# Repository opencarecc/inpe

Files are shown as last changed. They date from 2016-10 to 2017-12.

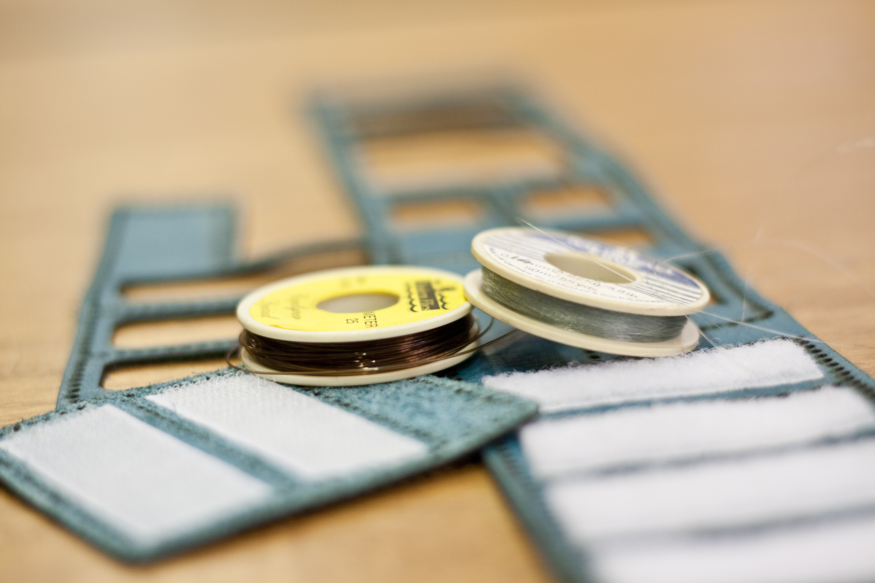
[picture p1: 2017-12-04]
pictures/_MG_0598.jpg

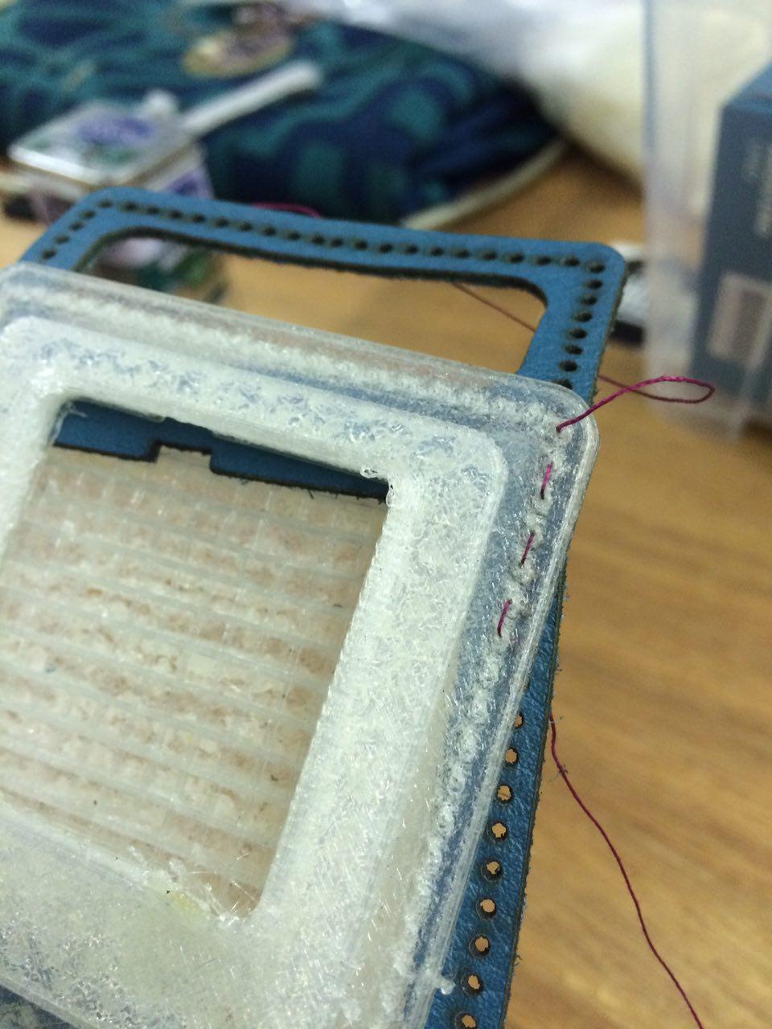
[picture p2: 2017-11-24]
pictures/Inpe_confezione.jpg

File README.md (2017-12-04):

# InPe' @ opencare.cc
InPe' is a wearable device that detects fall and call for emergecy.

InPe' has been ideated and designed by communities living in the city of Milan (Italy), and developed by [WeMake](http://wemake.cc/) in the framework of the [opencare.cc](http://opencare.cc/) project.

InPe' is open source. Please read below for licensing details.

## References
* More info about the opencare.cc project can be found here <http://opencare.cc>
* More info about the InPe' prototype can be found here <http://inpe.opencare.cc>
* Tutorials about InPe' can be found here <https://github.com/opencarecc/inpe/wiki>

## Software
The InPe' prototype is built on top of the *RePhone* hardware by Seeed Studio.
More info on how to get started with the RePhone and the RePhone development environment can be found in the wiki section of the repo <https://github.com/opencarecc/inpe/wiki>

In the **software** folder of the repository are various Arduino *.ino* sketches, all of them can be ran by the RePhone hardware:
* in the **software** root folder are the updated main sketches of the InPe' prototype (the "InPe-T\*" versions have been implemented for the user testing campaign)
* in the **utilities** folder is a collection of sketches to test, calibrate and debug the hardware. They are useful to setup and customize an InPe', and for developers willing to contribute to the project to learn more about the library.

## Hardware
In the hardware section of the repository are the source files for the case *[coming soon...]*

## Bug reporting and Contributions
If you want to report a bug please do so in the *[Issues](https://github.com/opencarecc/inpe/issues)* section of the repository (<https://github.com/opencarecc/inpe/issues>) and mark it with a *BUG* label. Before adding a bug please do a quick search under the *BUG* label to check for known issues and avoid duplicates.

If you want to contribute please have a look under the *TO DO* and *WISH* labels to see what features are in the pipeline and what is the status of their development.

If you want to contribute with a new feature please open a new issue under the *PROPOSAL* label explaining about it.

## License

Copyright (C) 2016 WeMake

### Software

This program is free software: you can redistribute it and/or modify it under the terms of the [GNU General Public License](https://www.gnu.org/licenses/gpl-3.0.en.html) as published by the Free Software Foundation, either version 3 of the License, or any later version.

This program is distributed in the hope that it will be useful, but WITHOUT ANY WARRANTY; without even the implied warranty of MERCHANTABILITY or FITNESS FOR A PARTICULAR PURPOSE.  See the
    GNU General Public License for more details.

You should have received a copy of the GNU General Public License along with this program.  If not, see <http://www.gnu.org/licenses/>.

### Hardware

Copyright 2016 WeMake.

This documentation describes an Open Hardware and is licensed under the CERN OHL v. 1.2.

You may redistribute and modify this documentation under the terms of the CERN OHL v.1.2. ([http://ohwr.org/cernohl]()). 
This documentation is distributed WITHOUT ANY EXPRESS OR IMPLIED WARRANTY, INCLUDING OF MERCHANTABILITY, SATISFACTORY QUALITY AND FITNESS FOR A PARTICULAR PURPOSE. Please see the CERN OHL v.1.2 for applicable conditions

## Contacts

You can get in touch with us on the InPe' [website](http://inpe.opencare.cc/#comments) or by writing at: 
opencare [@] wemake [dot] cc

-----



This project has received funding from the European Union's Horizon 2020 research and innovation programme under grant agreement No 688670.

-----

*THANKS!*

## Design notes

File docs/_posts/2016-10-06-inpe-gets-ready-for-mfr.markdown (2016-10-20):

---
layout: post
title:  "In Pe gets ready for Maker Faire Rome"
date:   2016-10-06
categories: 
---

It has been several weeks now of In Pe development and we are getting close to finalizing our initial prototype before the Rome Makerfaire.  As you know, In Pe is a device developed as a result of WeMake’s hosted codesign sessions. It is based on a real story, where a caregiver was about to loose her mother, who fell down while being alone, and the caregiver couldn’t be alarmed. The existing market solutions are sometimes “embarrassing” or not appealing enough or not comfortable to wear, which makes them less efficient, as the person in need of care, will simply avoid them. In Pe (which means Standing Up
in Italian), is a simple opensource, customizable device, that can help caregiver stay in touch with their loved ones, while keeping in mind that the designed solution is appealing enough for the person who needs care, so that they are actually using it.

Our solution simply depends on detecting a fall and calling a caregiver. Once the fall is detected, then this person will receive a call that the person fell down and the caregiver can react.   Our particular solution is  designed as a bracelet that the elderly or person who needs care can wear in his wrist, but we are currently checking other forms of usability that can fit different needs.

The project is composed of a sensor that detects the fall, a GSM module that sends a signal when a fall action is detected, and then the caregiver received a call.   All hardware and code is opensource.  It is not a newbie level kind of opensource project, but through documentation and some makerspace/fablab help, any caregiver is able to replicate and personalize it.

We are currently in testing phase where we are checking both the usability and the sensor accuracy.   We are testing different falling scenarios, such as testing to detect a fall while skateboarding, for example, we are also testing different usability scenarios, to check if the device could be sued for individuals with different needs.

Moving on, we will be developing different iterations of the device in order to both meet different needs of functionalities and to provide a different appeal for In Pe.  The Rome MakerFaire is almost a week ahead, where we look forward to have a chance to present our concept to a broad audience, receive more feedback, and get in touch with more future testers or replicators. Stay tuned to our next updates.

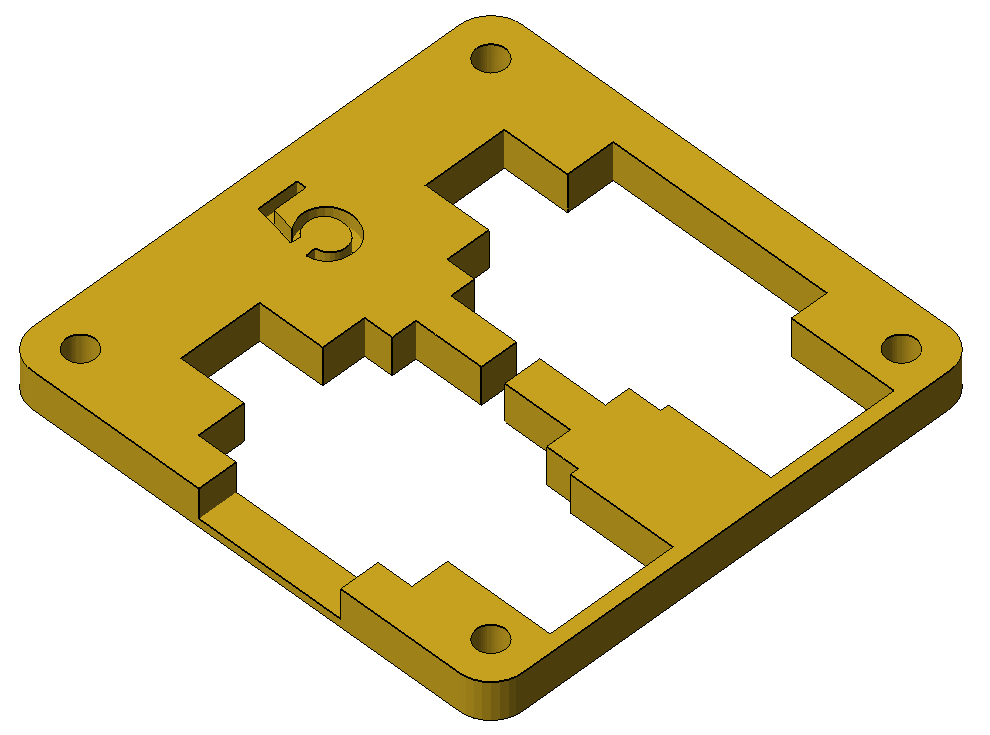
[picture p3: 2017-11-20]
pictures/InPe Layer 05.png

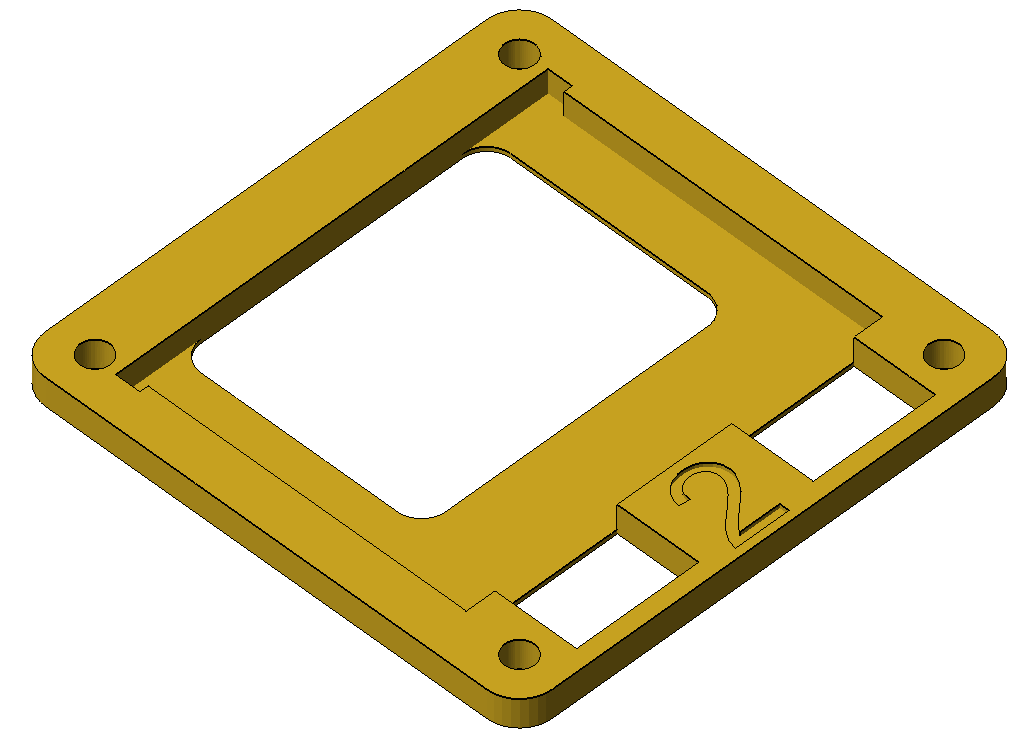
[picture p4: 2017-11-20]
pictures/InPe Layer 02.png

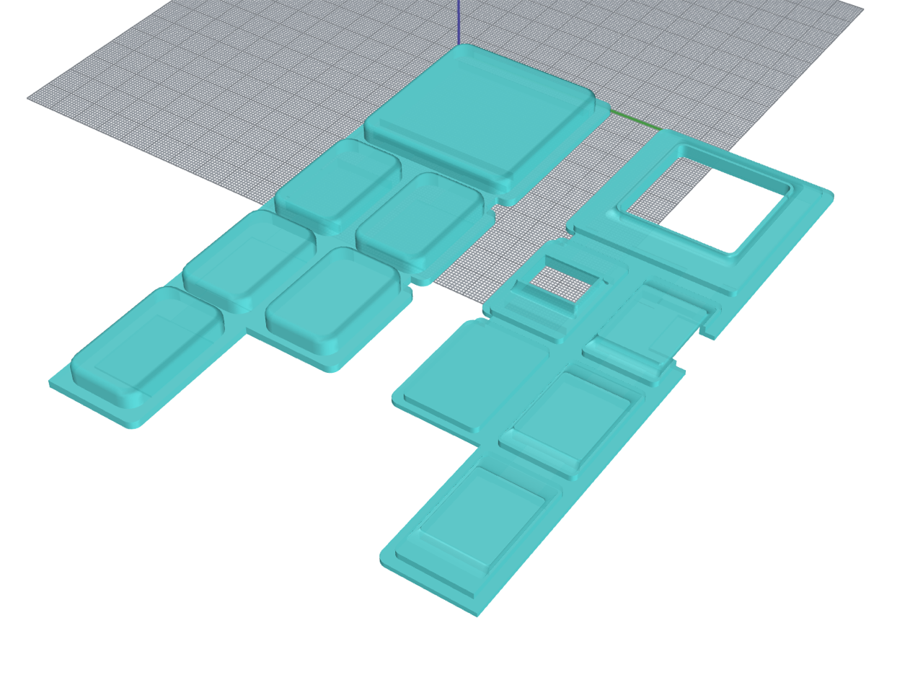
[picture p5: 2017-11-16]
pictures/Screen Shot 2017-11-15 at 20.33.19.png

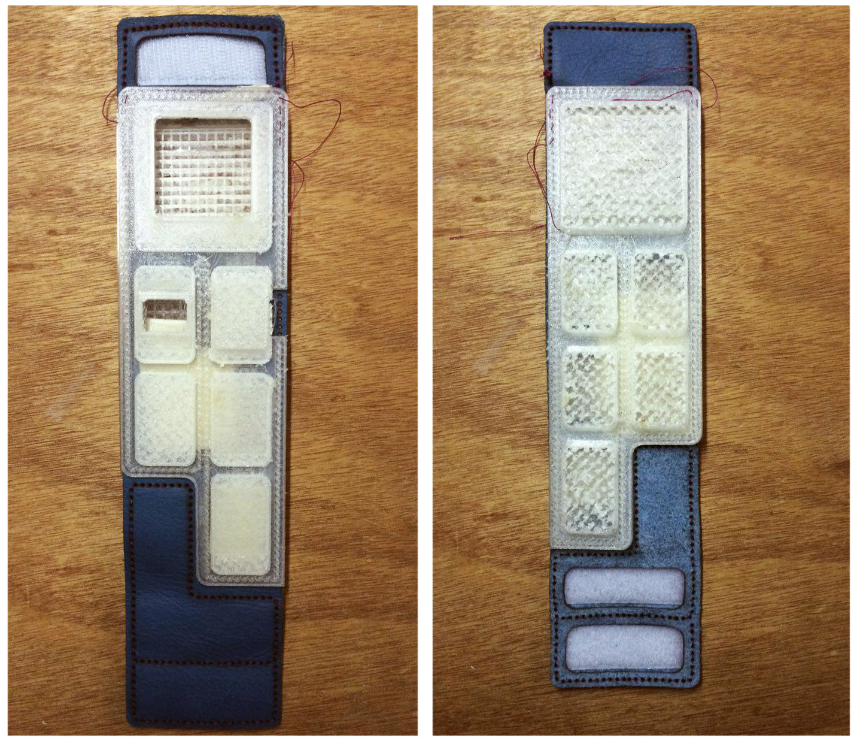
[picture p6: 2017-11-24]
pictures/Inpetest2.jpg

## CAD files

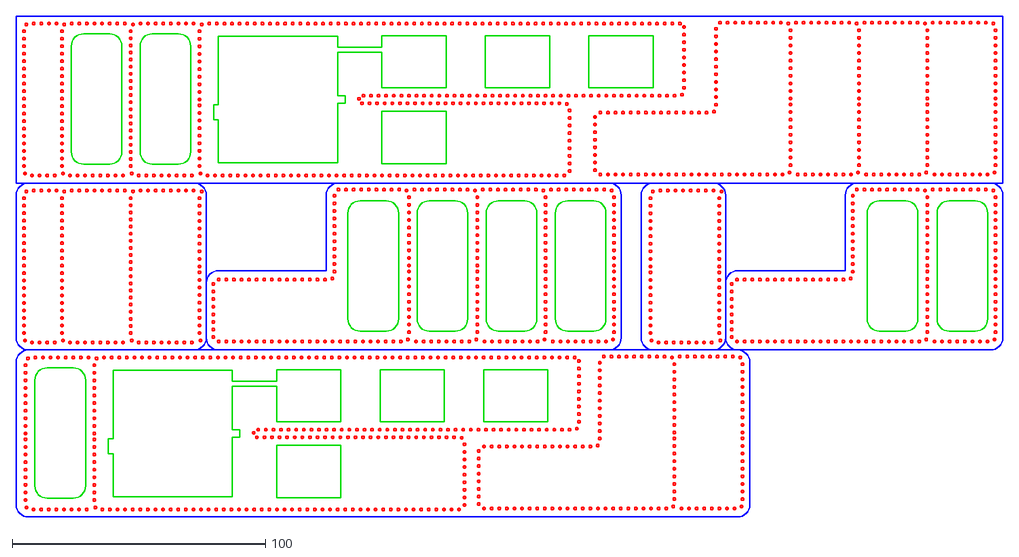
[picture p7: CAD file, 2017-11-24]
3Dmodels/IpEWristwatch.dxf
390.0 x 198.0

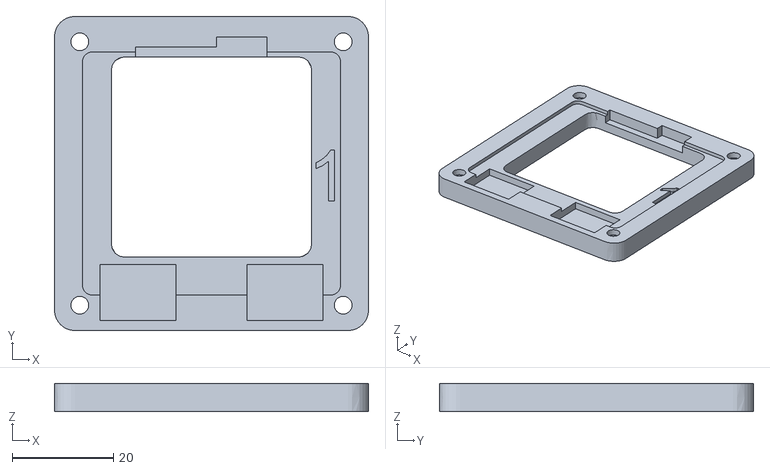
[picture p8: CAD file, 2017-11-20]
3Dmodels/inpe_ inner case 01.stl
62.0 x 62.0 x 5.60

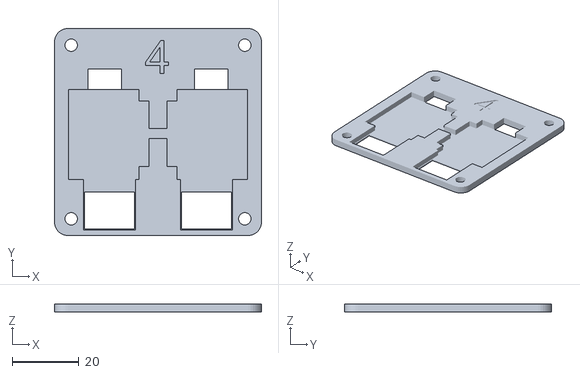
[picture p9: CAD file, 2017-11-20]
3Dmodels/inpe_ inner case 04.stl
62.0 x 62.0 x 2.50

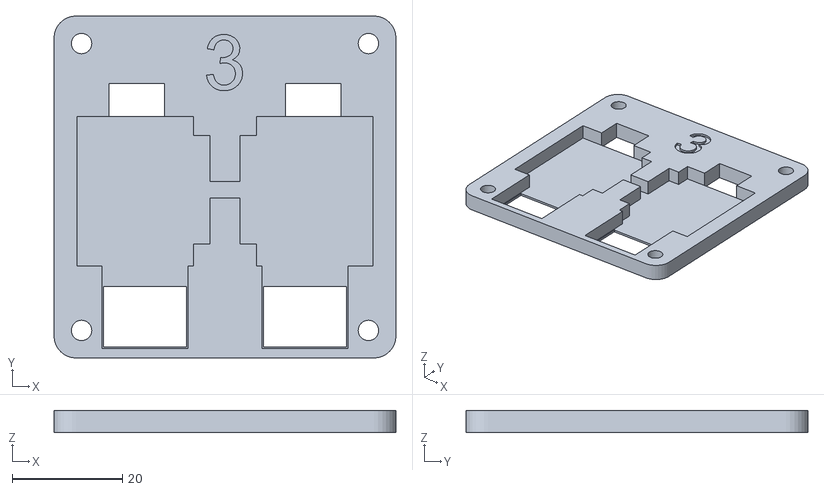
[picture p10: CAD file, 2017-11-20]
3Dmodels/inpe_ inner case 03.stl
62.0 x 62.0 x 4.00

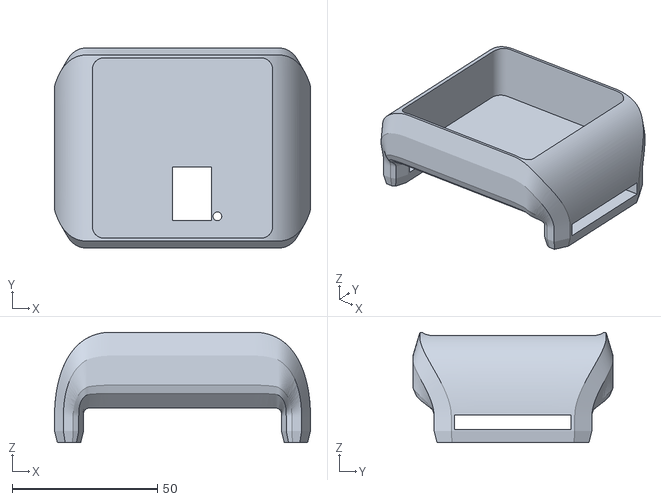
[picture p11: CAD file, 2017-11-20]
3Dmodels/inpe_ outer case 02.stl
88.0 x 68.8 x 38.0

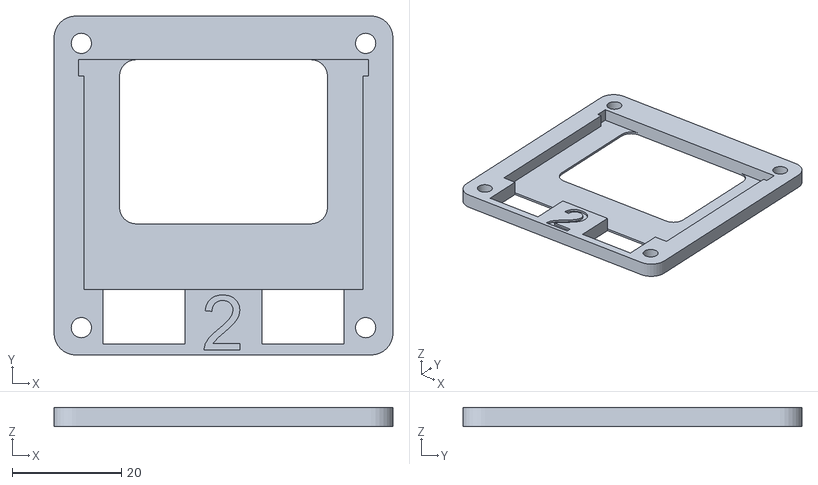
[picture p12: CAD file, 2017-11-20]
3Dmodels/inpe_ inner case 02.stl
62.0 x 62.0 x 3.50

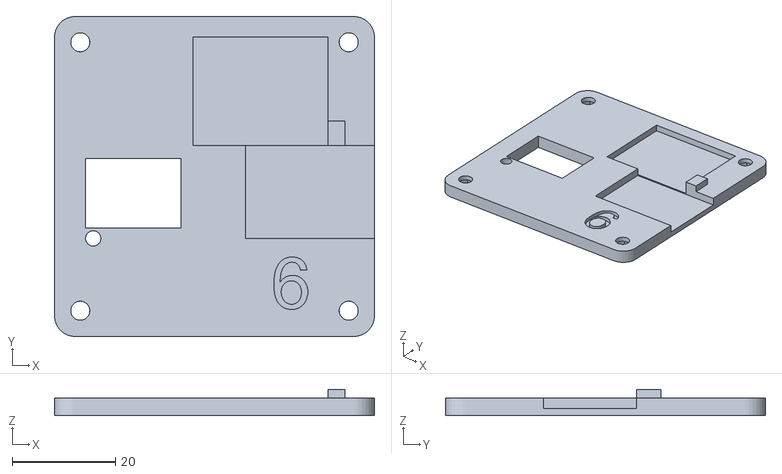
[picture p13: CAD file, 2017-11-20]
3Dmodels/inpe_ inner case 06.stl
62.0 x 62.0 x 5.10

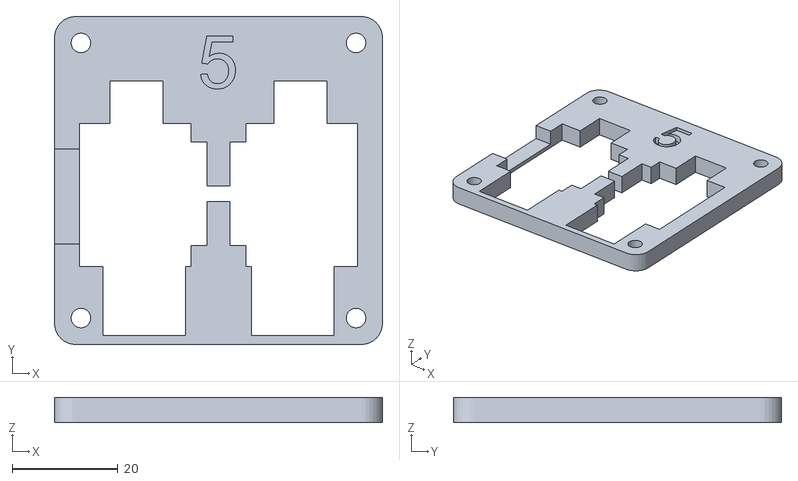
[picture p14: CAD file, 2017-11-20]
3Dmodels/inpe_ inner case 05.stl
62.0 x 62.0 x 4.80

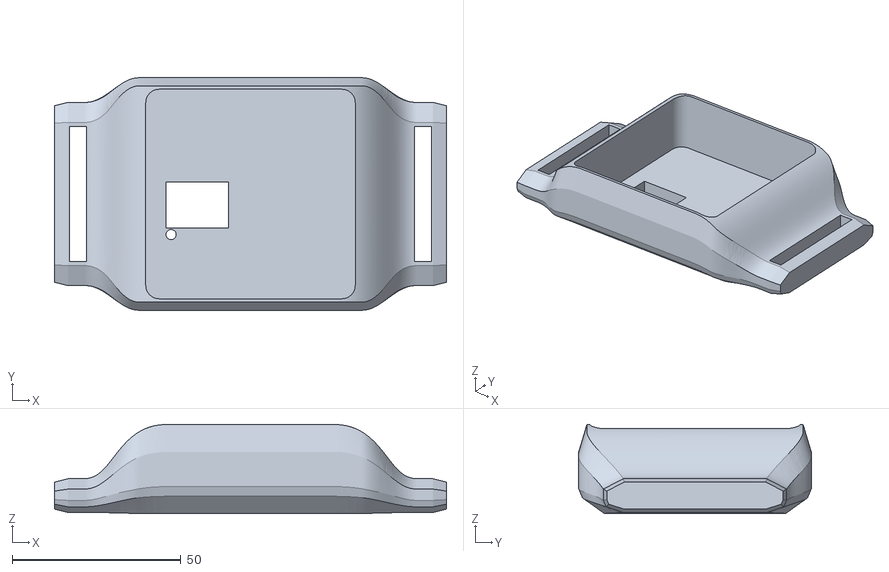
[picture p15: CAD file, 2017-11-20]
3Dmodels/inpe_ outer case 01.stl
116.0 x 68.8 x 26.4

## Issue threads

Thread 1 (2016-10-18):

fix fall detection algorithm

cntlsn, 2016-10-18:

cntlsn, 2016-12-06:
first iteration of the fall detection algorithm according to http://www.analog.com/en/analog-dialogue/articles/detecting-falls-3-axis-digital-accelerometer.html can be found here https://github.com/opencarecc/inpe/commit/b9420b699cf71949d21788917aed711021cbde0d

despite being more accurate, we decided to NOT go the interrupts way to make it more simple for future users to install their InPe' software

cntlsn, 2017-02-07:
fall detection algorithm according to http://www.analog.com/en/analog-dialogue/articles/detecting-falls-3-axis-digital-accelerometer.html can be found here https://github.com/opencarecc/inpe/commit/36d10e706345a82c4b3d9669377255bc116b8708

Closed 2017-02-07.

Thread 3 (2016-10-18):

rewrite GPS localization to save battery power

cntlsn, 2016-10-18:

cntlsn, 2016-12-06:
the first iteration can be found here https://github.com/opencarecc/inpe/commit/d5df8482466e7053867ff91c11b2a4eface8cad1
a clock library has been created. it keeps waiting for the GPS to pass UTC data, then starts a counter and displays the time on the LCD

cntlsn, 2016-12-06:
a second iteration can be found here https://github.com/opencarecc/inpe/commit/a7044c83d79ca759f0935d4938db9807c36e7a4e
it keeps waiting for the GPS to pass the UTC data, then sets the date and time using the DateTime library.
the DateTime library takes care of updating the time and date values

Closed 2017-02-07.

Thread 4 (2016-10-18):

turn off LCD display when not in use to save battery power

cntlsn, 2016-10-18:

cntlsn, 2016-12-06:
this has been solved in two ways

in https://github.com/opencarecc/inpe/commit/9147f1a338dcbac8146ef5f57f2e43f33f45e05f the sketch is just turning the backlight of the LCD up and down

in https://github.com/opencarecc/inpe/commit/54f33ccb3a6ad1112db7e96af79d8f1a146900ca the sketch is using the fuctions vm_pwr_lcd_sleep_in/out to turn the LCD on or off, but for some reason the LCD backlight stays always on.

this needs confirmation of power consumption in both approaches!

cntlsn, 2017-02-07:
solved with https://github.com/opencarecc/inpe/commit/5b25ce85826d4fd4b7289301ffba7571788a2cc8

Closed 2017-02-07.

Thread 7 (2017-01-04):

Create sketch to log power consumption with new Sleep Library

cntlsn, 2017-01-04:
Sleep library is here https://github.com/opencarecc/inpe/tree/5b25ce85826d4fd4b7289301ffba7571788a2cc8/software/utilities/Sleep_Library

cntlsn, 2017-01-05:
the cketch can be found here https://github.com/opencarecc/inpe/tree/a29eb10f5f5725b85c05a5a3da166cbd71b6fd56/software/utilities/Sleep_Library-Battery_Log

Closed 2017-01-05.

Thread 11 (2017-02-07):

[0.1-t03_10] sensor hub goes offline

cntlsn, 2017-02-07:
when removing/commenting the display on LCD of the Accelerometer Inactivity delta on line 403, the sensor hub tends go offline every once in a while for a some milliseconds

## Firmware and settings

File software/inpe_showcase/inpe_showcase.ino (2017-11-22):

/*
  This sketch is a fake version of InPe.
  It would turn useful when showing how it works to
  people at events without asking them to necessarily
  fall to the ground ;)
  
  HARDWARE:
  - Xadow GSM+BLE (with Antenna!)
  - Xadow 1.54" Touchscreen
  - Xadow Audio
  - Xadow GPS
  - Xadow Basic Sensors
  - Lipo battery 3.7v 520mAh
  - MicroSIM card
  
  !! ATTENTION !!
  To run this sketch extra libraries are required.
  - Please find them at https://github.com/opencarecc/inpe/tree/master/software/libraries
  Before uploading the sketch, please:
  - enter your phone number
  - enter date and time
  
  Alessandro Contini @ WeMake for http://opencare.cc/
  2017
*/

#include "LDisplayExt.h"
#include <LSensorHub.h>
#include <LAudio.h>
#include <LGTouch.h>
#include <LGPS.h>
#include <stdio.h>
#include <LCheckSIM.h>
#include <LGSM.h>
#include <LBattery.h>
//#include <LCFile.h>
#include <LDateTime.h>
#include "LSleep.h"

// initialize variables for GSM
char *phoneNumber = "enter-phone-number";

// initialize variables for Date and Time
// set time
unsigned int year     = 2017;
unsigned int month    = 11;
unsigned int day      = 6;
unsigned int hour     = 18;
unsigned int minute   = 7;
unsigned int sec      = 22;

datetimeInfo t;

char date[11];
char time[10];

// initialize variables for GPS UTC time data reading
unsigned char *utc_date_time = 0;
char bufferDateTime[30] = {0,};

unsigned int GPSyear      = 0;
unsigned int GPSmonth     = 0;
unsigned int GPSday       = 0;
unsigned int GPShour      = 0;
unsigned int GPSminute    = 0;
unsigned int GPSsec       = 0;

const int timeZone = +1;  // add here the amount of hours difference of your time zone compared to GMT
                          // if not sure about your time zone try this http://everytimezone.com/

boolean GPSDateTimeSynced = false;
boolean GPStimeConverted = false;

// initialize variables for audio module
#define    FILE_NAME    "rephone_audio.mp3"
int volume = 6;  // 0 is min, 6 is max volume

// initialize variables for touch event
char EVENT = 0;
int X = 0;
int Y = 0;

// initialize variables for accelerometer data
long accData1 = 0;  // will be used for X axis values
long accData2 = 0;  // will be used for Y axis values
long accData3 = 0;  // will be used for Z axis values

boolean fallFlag = false;   // alarm screen flag

boolean systemFlag = false; // system check flag

//boolean testFlag = false;   // test mode flag

// string to save the SMS SENT or NOT SENT data
char *SMSsentFeedback;
boolean smsSent = false;  // check to send SMS only once

// string to save the System Ready or System Error data
char *systemCheck;
unsigned int systemCheckStatus = 0;

// string to save the Sensor Hub Status (ON/OFF) data 
char *sensorHubStatus;
// string to save the GPS (ON/OFF) data 
char *GPSState;
// string to save the GPS (Sync/Ready/Error) data 
char *GPSStatus;

// string to save the SIM Status (OK/Error) data 
char *SIMStatus;

// set min and max coordinates for easier positioning on LCD screen
int xInit = 0;
int yInit = 0;
int xFinal = 240;
int yFinal = 240;



/* TEST MODE - FILE LOG STUFF */
// set a delay time to avoid flooding the log
int delayTime = 100;
// check number of loop runs
int numAccPrintRuns = 0;
int maxAccPrintRuns = 1;
// array to store chars for the file name
char fileName[21] = {0,};
// array to store chars for the heading of the txt file
char fileHeader[100] = {0,};
char writedata[40] = {0};  // will be used to print int the txt
// array to store the fall detection values
char detected[100] = {0, };
// var to store the status of Test Mode (0=OFF/1=ON) 
int testModeStatus = 0;

//////////////////////////////////////////////////////////
///////////////////////   SETUP   ////////////////////////
//////////////////////////////////////////////////////////

void setup()
{
  Serial.begin(115200);

  // Initialize Audio module
  LAudio.begin();
  LAudio.setVolume(volume);
  // play audio file to notify audio system is ready and device is ON
  LAudio.playFile(storageFlash, (char*)FILE_NAME);  

  // initialize touch
  Tp.Init();

  // initialize LCD
  LcdExt.init();
  LcdExt.font_init();
  LcdExt.back_light_level(100);
  LcdExt.screen_set(0x000000);

  // initialize Date and Time
  time_init();
  LDateTime.setTime(&t);
}

//////////////////////////////////////////////////////////
///////////////////////   LOOP   /////////////////////////
//////////////////////////////////////////////////////////

void loop()
{
  // check modules are connected and ready
  checkSensorHub();
  checkGPS();
  checkSIM();

  // show visual feedback if system ready or not
  checkSystem();

  // build home screen
  homeScreen();
  
  LcdExt.draw_updata();  // update screen 
}


//////////////////////////////////////////////////////////
////////////////   CHECK ACCELEROMETER   /////////////////
//////////////////////////////////////////////////////////
/* Check if Accelerometer is working */
boolean checkSensorHub() {
  switch(LSensorHub.check_on_line()){
    /* if Sensor Hub is not connected */
    case 0:                                           
      sensorHubStatus = "OFF  ";
      return false;
      break;
    /* if Sensor Hub is connected */
    case 1:                                           
      LSensorHub.GetAccData(&accData1, &accData2, &accData3);
      /* and if you are receiving values different than zero from the Accelerometer */  
      if (accData1!=0 && accData2!=0 && accData3!=0) {
        sensorHubStatus = "ON   ";
        return true;
        break;
      } else {
        sensorHubStatus = "ERROR";
        return false;
        break;
      }
      break;
  }
}


//////////////////////////////////////////////////////////
/////////////////////   CHECK GPS   //////////////////////
//////////////////////////////////////////////////////////
/* Check if GPS is working */
boolean checkGPS() {  
  switch(LGPS.check_online()){
    /* if GPS module is not connected */
    case 0:
      GPSState = "OFF";
      Serial.println("GPS is OFF");
      return false;
      break;
    /* if GPS module is connected */
    case 1:
      GPSState = "ON  ";
      /* if GPS Status is V(=navigation receiver warning) */
      if (LGPS.get_status()==86) {
          GPSStatus = "Sync  ";
          Serial.println("GPS is V");
      }
      /* if GPS Status is A(=Valid position) */
      else if (LGPS.get_status()==65) {
        GPSStatus = "Ready";
        Serial.println("GPS is A");
        return true;        
        break;
      } else {
        GPSStatus = "Error";
        Serial.println("GPS is ERROR");
      }
      break;
  }  
}


//////////////////////////////////////////////////////////
/////////////////////   CHECK SIM   //////////////////////
//////////////////////////////////////////////////////////
/* Check if a SIM card is inserted */
boolean checkSIM() {
  switch(LCheckSIM.isCheck()){
    /* if SIM is not inserted */
    case 0:
      SIMStatus = "Error";
      return false;
      break;
    /* if SIM is inserted */
    case 1:
      SIMStatus = "OK   ";
      return true;
      break;
  }
}


//////////////////////////////////////////////////////////
///////////////////   CHECK SYSTEM   /////////////////////
//////////////////////////////////////////////////////////
/* 
   If Xadow modules are connected and receiving
   correct data show visual feedback
*/
void checkSystem(){
  if(checkSensorHub()==true && checkGPS()==true && checkSIM()==true){
    systemCheck = "Ready :)";
    // if GPS available sync time with GPS UTC time
    GPStimeSync();      
//    return true;
    systemCheckStatus = 1;
  } else if(checkSensorHub()==true && checkGPS()==false && checkSIM()==true){
    systemCheck = "Ready :)";
    systemCheckStatus = 2;
  } else {
    systemCheck = "Error :(";
//    return false;
    systemCheckStatus = 3;
  }
}


//////////////////////////////////////////////////////////
////////////////////   HOME SCREEN   /////////////////////
//////////////////////////////////////////////////////////
void homeScreen(){
  Serial.println("Into Home Screen");
  
  // flush content by creating a new background
//  draw_rect(0,30,240,210,0x000000);
  LcdExt.draw_fill_rectangle(0,30,240,210,0x000000,0x000000);
  
  while(systemFlag==false && fallFlag==false){
    Serial.println("Into Home Screen While");
    
    createHeader();
    displayDate();
    displayTime();
    
    LcdExt.draw_font(87, 125, "InPe is", 0, 0xffffff, 20);
    if(checkSystem()==true){
      // font color green
//      draw_rect(50,150,147,40,0x000000);
      LcdExt.draw_fill_rectangle(50,150,147,40,0x000000,0x000000);
      LcdExt.draw_font(82, 150, systemCheck, 0, 0x00ff00, 20);
    } else {
      // font color red
//      draw_rect(50,150,147,40,0x000000);
      LcdExt.draw_fill_rectangle(46,150,152,50,0x000000,0x000000);
      LcdExt.draw_font(85, 150, systemCheck, 0, 0xff0000, 20);

      LcdExt.draw_fill_rectangle(46,173,150,25,0xff0000,0xff0000);
      LcdExt.draw_font(50, 177, "Check System", 0xff0000, 0x000000, 20);
      LcdExt.draw_fill_triangle(185,181,190,186,185,191,0x000000,0x000000);
    }

    displayAlarmTrigger();
    
    if (Tp.Event_available()) {
      lsleep.sleep();   // we also need to call the sleep function here otherwise it will not wake up
      Tp.Get_event_xy(&EVENT, &X, &Y);
      triggerCheckScreen();    
      if(triggerFall()==true){
        Serial.println("Fall triggered");
        fallFlag = true;
        doTheAlarm();
      }  
    }
//    testMode();

    // call sleep function
    lsleep.sleep();

    LcdExt.draw_updata();
  }   
}

/* ==== UI HEADER ==== */
void createHeader(){
//  draw_rect(0, 0, 240, 30, 0xffffff);
  LcdExt.draw_fill_rectangle(0, 0, 240, 30, 0xffffff, 0xffffff);
  batteryLevel();
}
void displayDate(){
  LDateTime.getTime(&t);
  sprintf(date, "%02u-%02u-%02u", t.year, t.mon, t.day);
  LcdExt.draw_font(8, 8, date, 0xffffff, 0x000000, 18);
}
void displayTime(){
  LDateTime.getTime(&t);
  sprintf(time, "%02u:%02u", t.hour, t.min);
  LcdExt.draw_font(55, 65, time, 0, 0xffffff, 50);
  sprintf(time, "%02u", t.sec);
  LcdExt.draw_font(182, 65, time, 0, 0xffffff, 18);
}

/* ==== BATTERY ==== */
void batteryLevel(){
  // draw battery icon
//  draw_rect((xFinal)-48,5,35,20,0x000000);
//  draw_rect((xFinal)-13,8,4,14,0x000000);
//  draw_rect((xFinal)-45,8,29,14,0xffffff);
  LcdExt.draw_fill_rectangle((xFinal)-48,5,35,20,0x000000,0x000000);
  LcdExt.draw_fill_rectangle((xFinal)-13,8,4,14,0x000000,0x000000);
  LcdExt.draw_fill_rectangle((xFinal)-45,8,29,14,0xffffff,0xffffff);
    
  // check if battery is charging
  if(LBattery.isCharging()){
    // draw charging icon
    // this is pretty experimental, need to find a better algorithm
    float k = 6;
    float h = 21;
    for(unsigned char x=0;x<20;x++){
      k=k-0.7;
      for(float y=0;y<k;y++){
        LcdExt.draw_point(x+(xFinal-32),y+14,0x000000);
      }
    }
    for(unsigned char x=0;x<20;x++){
      h=h-0.7;
      for(float y=12;y>h;y--){
        LcdExt.draw_point(x+(xFinal-49),y+2,0x000000);
      }
    }
  } else {
    // fill battery icon from L to R according to battery level
    if (LBattery.level()==0){
//      draw_rect((xFinal)-43,10,3,10,0xff0000);
      LcdExt.draw_fill_rectangle((xFinal)-43,10,3,10,0xff0000,0xff0000);
    }
    if (LBattery.level()==33){
//      draw_rect((xFinal)-43,10,10,10,0xff0000);
      LcdExt.draw_fill_rectangle((xFinal)-43,10,10,10,0xff0000,0xff0000);
    }
    if (LBattery.level()==66){
//      draw_rect((xFinal)-43,10,18,10,0x000000);
      LcdExt.draw_fill_rectangle((xFinal)-43,10,18,10,0x000000,0x000000);
    }
    if (LBattery.level()==100){
//      draw_rect((xFinal)-43,10,25,10,0x000000);
      LcdExt.draw_fill_rectangle((xFinal)-43,10,25,10,0x000000,0x000000);
    }
  }
}


//////////////////////////////////////////////////////////
////////////////   SYSTEM CHECK SCREEN   /////////////////
//////////////////////////////////////////////////////////
/* ==== TRIGGER TO SYSTEM CHECK SCREEN ==== */
void triggerCheckScreen(){
  if (EVENT>0 && EVENT!=2 && X>=40 && X<=210 && Y>=140 && Y<=210) {
    systemFlag = true;
    systemCheckScreen();     
  }
}

/* ==== SYSTEM CHECK SCREEN ==== */
void systemCheckScreen() {  
  // flush content
//  draw_rect(0,30,240,210,0x000000);
  LcdExt.draw_fill_rectangle(0,30,240,210,0x000000,0x000000);

  while(systemFlag == 1){
    Serial.println("Into System Check Screen While");
    
    createHeader();
    displayDate();

    checkSensorHub();
    checkGPS();
    checkSIM();
    
    displaySensorHubValues();
    displayGPSData();
    displaySIM();
    
//    draw_rect((xFinal)-87, 205, 87, 40, 0xffffff);
    LcdExt.draw_fill_rectangle(163, 207, 77, 33, 0xffffff, 0xffffff);
    LcdExt.draw_font(184, 215, "Back", 0xffffff, 0x000000, 20);
    LcdExt.draw_fill_triangle(172,223,177,218,177,228,0x000000,0x000000);
    
    // if a touch event is detected
    if (Tp.Event_available()) {
      Tp.Get_event_xy(&EVENT, &X, &Y);
      if (EVENT > 0 && EVENT!=2 && X>=(xFinal)-87 &&  Y >= 220) {
        systemFlag = 0;
        homeScreen();     
      }
    }
    LcdExt.draw_updata();
  }
}

/* ==== DISPLAY SIM DATA ==== */
void displaySIM(){
  LcdExt.draw_font(10, 180, "SIM Status:", 0, 0xffffff, 20);
  if(LCheckSIM.isCheck()){
    LcdExt.draw_font(120, 180, SIMStatus, 0, 0xffffff, 20);
  } else {
    LcdExt.draw_font(120, 180, SIMStatus, 0, 0xff0000, 20);
  }
}

/* ==== DISPLAY GPS DATA ==== */
void displayGPSData() {
  LcdExt.draw_font(10, 110, "GPS:", 0, 0xffffff, 20);
  if (LGPS.check_online()){
    // if GPS is connected display GPSState in white
    LcdExt.draw_font(60, 110, GPSState, 0, 0xffffff, 20);
  } else {
    LcdExt.draw_font(60, 110, GPSState, 0, 0xff0000, 20);
  }  
  char GPSDataBuffer[50] = {0,};
  sprintf(GPSDataBuffer, "Status: %c\r\n", LGPS.get_status());
  LcdExt.draw_font(120, 110, GPSDataBuffer, 0, 0xffffff, 20);
  sprintf(GPSDataBuffer, "Lat %c:%f\r\n", LGPS.get_ns(), LGPS.get_latitude());
  LcdExt.draw_font(10, 130, GPSDataBuffer, 0, 0xffffff, 20);
  sprintf(GPSDataBuffer, "Long %c:%f\r\n", LGPS.get_ew(), LGPS.get_longitude());
  LcdExt.draw_font(10, 150, GPSDataBuffer, 0, 0xffffff, 20);
}

/* ==== DISPLAY SENSOR HUB VALUES ==== */
 void displaySensorHubValues() {
    // get data from sensors
    LSensorHub.GetAccData(&accData1, &accData2, &accData3);
    LcdExt.draw_font(10, 40, "Accelerometer:", 0, 0xffffff, 20);
    if(checkSensorHub()){
      // if SensorHub is connected display sensorHubStatus in white
      LcdExt.draw_font(150, 40, sensorHubStatus, 0, 0xffffff, 20);
    } else {
      // if SensorHub is connected display sensorHubStatus in red
      LcdExt.draw_font(150, 40, sensorHubStatus, 0, 0xff0000, 20);
    }
/* print Acc X value to LCD */
    LcdExt.draw_font(10, 60, "X:", 0, 0xffffff, 20);
    if(accData1 > 0){
        LcdExt.draw_font(10, 80, "+", 0, 0xffffff, 20);
        LcdExt.draw_number(20, 80, accData1, 0, 0xffffff, 20);
    } else {
        accData1 ^= 0xffffffff;
        accData1 += 1;
        LcdExt.draw_font(10, 80, "-", 0, 0xffffff, 20);
        LcdExt.draw_number(20, 80, accData1, 0, 0xffffff, 20);
    }

/* print Acc Y value to LCD */
    LcdExt.draw_font((xFinal/2)-20, 60, "Y:", 0, 0xffffff, 20);
    if(accData2 > 0){
        LcdExt.draw_font((xFinal/2)-20, 80, "+", 0, 0xffffff, 20);
        LcdExt.draw_number((xFinal/2)-10, 80, accData2, 0, 0xffffff, 20);
    } else {
        accData2 ^= 0xffffffff;
        accData2 += 1;
        LcdExt.draw_font((xFinal/2)-20, 80, "-", 0, 0xffffff, 20);
        LcdExt.draw_number((xFinal/2)-10, 80, accData2, 0, 0xffffff, 20);
    }

/* print Acc Z value to LCD */
    LcdExt.draw_font((xFinal)-50, 60, "Z:", 0, 0xffffff, 20);
    if(accData3 > 0){
        LcdExt.draw_font((xFinal)-50, 80, "+", 0, 0xffffff, 20);
        LcdExt.draw_number((xFinal)-40, 80, accData3, 0, 0xffffff, 20);
    } else {
        accData3 ^= 0xffffffff;
        accData3 += 1;
        LcdExt.draw_font((xFinal)-50, 80, "-", 0, 0xffffff, 20);
        LcdExt.draw_number((xFinal)-40, 80, accData3, 0, 0xffffff, 20);
    }
}


//////////////////////////////////////////////////////////
///////////////////////   ALARM   ////////////////////////
//////////////////////////////////////////////////////////
/* ==== FALL TRIGGER ==== */
void displayAlarmTrigger() {
//  draw_rect(220,220,20,20,0xff0000);
  LcdExt.draw_fill_ellipse(220,220,15,15,0x202020,0x202020);
}

boolean triggerFall() {
//  if (EVENT>0 && EVENT!=2 && X>=0 && X<=240 && Y>=0 && Y<=40) {
if (EVENT>0 && EVENT!=2 && X>=210 && X<=240 && Y>=210 && Y<=240) {   
//      sprintf(detected, "DETECTED!\r\non %d-%d-%d %d:%d:%d\r\nat LAT %c:%f LONG %c:%f\r\n", utc_date_time[0], utc_date_time[1], utc_date_time[2], utc_date_time[3], utc_date_time[4], utc_date_time[5], LGPS.get_ns(), LGPS.get_latitude(), LGPS.get_ew(), LGPS.get_longitude());
//      LFile.Write(fileName, detected);
    return true; 
  } else {
    return false;
  }
}

/* ==== START ALARM ==== */
void doTheAlarm() {
  Serial.println("Into Alarm");

  // switch screen color
//  draw_rect(0,0,240,240,0xff007f);
  LcdExt.draw_fill_rectangle(0,0,240,240,0xff007f,0xff007f);
  
  while(fallFlag==true){
  Serial.println("Into Alarm While");
  
  // display triggered text
  LcdExt.draw_font(15, 40, "FALL DETECTED!", 0xff007f, 0, 26);
  //  Lcd.draw_font(80, 80, "Calling", 0xff007f, 0);
  //  Lcd.draw_font(50, 80, SMSsentFeedback, 0xff007f, 0);
  LcdExt.draw_font(50, 100, "  SMS sent to:", 0xff007f, 0, 20);
  LcdExt.draw_font(40, 120, phoneNumber, 0xff007f, 0, 20);
  
  // play audio file
  Serial.println("Play the audio");
  AudioStatus status;
  LAudio.playFile(storageFlash, (char*)FILE_NAME);

  delay(1000);
  
  // if not into TEST MODE
//  if (testFlag==0){
//    Lcd.draw_font(60, 200, "touch to stop", 0xff007f, 0, 20);
//  }
//  if (testFlag==1){
//    Lcd.draw_font(60, 140, "Confirm fall?", 0xff007f, 0, 20);
//    draw_rect((xFinal/2)-80,170,60,60,0x000000);
//    Lcd.draw_font((xFinal/2)-70, 190, "YES", 0x000000, 0xff007f, 20);
//    draw_rect((xFinal/2)+20,170,60,60,0x000000);
//    Lcd.draw_font((xFinal/2)+35, 190, "NO", 0x000000, 0xff007f, 20);
//  }

  LcdExt.draw_fill_rectangle(53,196,129,26,0x000000,0x000000);
  LcdExt.draw_font(60, 200, "touch to stop", 0, 0xff007f, 20);

  doSMS();

  delay(1000);
  
  // check touch event and exit triggered state if LCD is touched
  if (Tp.Event_available()) {
//    if (testFlag==0){
      Tp.Get_event_xy(&EVENT, &X, &Y);
      if (EVENT > 0 && EVENT!=2) {
        
        fallFlag = false;
        // close call
        LVoiceCall.hangCall();

        smsSent=false;
        
        homeScreen();
      }
//    } else
//    if (testFlag==1){
//      Tp.Get_event_xy(&EVENT, &X, &Y);
//      // if press Confirm YES
//      if (EVENT > 0 && EVENT!=2 && X>=(xFinal/2)-80 && X<=(xFinal/2)-20 && Y>=170 && Y<=230) {
//        draw_rect((xFinal/2)-80,170,60,60,0xffffff);
//        Lcd.draw_font((xFinal/2)-70, 190, "YES", 0xffffff, 0xff007f, 20);
//        LFile.Write(fileName, "[CONFIRMED]");
//        testFlag=0;
//        flag = 0;
//        homeScreen();
//      } else
//      if (EVENT > 0 && EVENT!=2 && X>=(xFinal/2)+20 && X<=(xFinal/2)+80 && Y>=170 && Y<=230) {
//        draw_rect((xFinal/2)+20,170,60,60,0xffffff);
//        Lcd.draw_font((xFinal/2)+35, 190, "NO", 0xffffff, 0xff007f, 20);
//        LFile.Write(fileName, "[NOT CONFIRMED]");
//        testFlag=0;
//        flag = 0;
//        homeScreen();
//      }
//    }
  }

LcdExt.draw_updata();
  }
}

/* ==== SEND SMS TO SELECTED NUMBER ==== */
void doSMS() {
  if(smsSent == false){
    char SMScontent[159] = {0,};

    if (checkGPS() == true){
      sprintf(SMScontent, "HELP! I fell here http://maps.google.com/maps?q=%f,%f", LGPS.get_latitude(), LGPS.get_longitude());
      Serial.print("SMS content: ");
      Serial.println(SMScontent);
    } else {    
      sprintf(SMScontent, "HELP! I have fallen");
      Serial.print("SMS content: ");
      Serial.println(SMScontent);
    }
  
    Serial.println("Sending SMS:");
//    while(!LSMS.ready()){}
    if(LSMS.ready()){
      Serial.println("SMS ready is ok");
  
      LSMS.beginSMS(phoneNumber);
      LSMS.print(SMScontent);
      
      if(LSMS.endSMS()){
        Serial.println("SMS is sent");
        SMSsentFeedback = "  SMS sent to:";
        smsSent = true;
      } else {
        Serial.println("SMS send fail");
        SMSsentFeedback = "SMS failed to:";
      }
    } else {
      Serial.println("SMS not ready");
      SMSsentFeedback = "SMS Error to:";
    }
  }
}

/* ==== START A CALL TO SELECTED NUMBER ==== */
void doTheCall() {
//Serial.println("do the call");
  // check if SIM is ready
  if (LCheckSIM.isCheck() == true) {
    Serial.println("Start call");
    // start call
    LVoiceCall.voiceCall(phoneNumber);
  }
}



//////////////////////////////////////////////////////////
////////////////////   DATE TIME   ///////////////////////
//////////////////////////////////////////////////////////

void GPStimeSync(){
  if(GPSDateTimeSynced==false){
      convertGPStimeToInt();
      time_init();
      LDateTime.setTime(&t);
      LcdExt.screen_set(0x000000);  // flush the screen
  }
}
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

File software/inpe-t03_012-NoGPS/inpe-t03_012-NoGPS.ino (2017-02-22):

#include <LSensorHub.h>

// initialize variables for accelerometer data
long accData1 = 0;  // will be used for X axis values
long accData2 = 0;  // will be used for Y axis values
long accData3 = 0;  // will be used for Z axis values
long prevData1 = 0;  // will be used for X axis values
long prevData2 = 0;  // will be used for Y axis values
long prevData3 = 0;  // will be used for Z axis values
long runningDelta = 0;

const long THRESH_FF = 250; // constant to check if free-fall is happening
const long FALLING_MINIMUM_TIME = 5;
const long FALLING_MAX_TIME = 200;
long freeFallCounter = 0;
bool accFallDetected = FALSE;
bool falling;

const long THRESH_IMPACT = 2000;  // constant to check if impact is happening
const long IMPACT_MAX_TIME = 3500;
bool impact;

const long THRESH_INACT = 187;
long INACT_MAX_TIME = 200;
bool inactivity;

int status = 0;
int fallingTime = 0;
int impactTime = 0;
int inactivityTime = 0;
boolean fallDetected;

// sensor_loop stuff
// -------------------------------------
extern volatile long accData[128][3];
extern volatile int lastRead;
int firstRead = 0;
extern "C" {
  unsigned char startSensorLoop(void *);
}
// -------------------------------------

/* ==== LOG and DISPLAY STUFF ==== */
#include <LCFileExt.h>
#include <LDisplay.h>

// variables for vertical positioning of on display feedback
int y = 150;
int y2 = 150;
int y3 = 0;

// array to store chars for the log file name
char fileName[100] = {0,};
int fileNum = 0;

// array to store chars for the heading of the log file
char fileHeader[100] = {0,};

char I_DONT_KNOW_WHAT_THIS_ARRAY_IS_DOING_BUT_IF_I_REMOVE_IT_THE_SKETCH_GETS_STUCK_IN_THE_FALL_DETECT_LOOP_SEE_LINE_176[200];

int accActivity;
int accState;
int algState;

int userConfirm;

boolean fileCreated = FALSE;

/* |||||||||||||||||||||||||||||||||||||||||||||||||||||||||||||||||||||||||||||||||||||||||| */
int writtenToFileNum = 0;

char dataToWrite[1000];
int dataWritten;

unsigned long writeCounter;
boolean arrayLapped;

unsigned long microsToWrite[10000];
long accDataToWrite[10000][3];
int activityToWrite[10000];
int accStateToWrite[10000];
int algStateToWrite[10000];
int fallTimeToWrite[10000];
int impactTimeToWrite[10000];
int inactTimeToWrite[10000];
int detectToWrite[10000];
int userConfirmToWrite[10000];
/* |||||||||||||||||||||||||||||||||||||||||||||||||||||||||||||||||||||||||||||||||||||||||| */

void draw_rect(int x, int y, int width, int height, uint32_t color) {
  Lcd.draw_fill_rectangle(x, y, (x + width), (y + height), color);
}

/*=== touch stuff ====*/
#include <LGTouch.h>
char EVENT = 0;
int X = 0;
int Y = 0;

char bufferTouchEvent[30] = {0,};
int touchEvent;

/*=== UI ====*/
boolean triggered = FALSE;
boolean triggeredFirstRun = FALSE;

void setup() {
  delay(10000);

  Serial.begin(115200);

  // initialize touch
  Tp.Init();

  Lcd.init();
  Lcd.font_init();
  Lcd.back_light_level(50);
  Lcd.screen_set(0x000000);
  LTask.remoteCall(startSensorLoop, NULL);

  Lcd.draw_updata();  // update LCD
}

void loop() {
  /* ==== LOG FILE CREATION AND LCD FEEDBACK STUFF ==== */
  if (LSensorHub.check_on_line() == TRUE) {
    Lcd.draw_font(10, 10, "-- Fall detection test --", 0x000000, 0xffffff, 20);

    if (fileCreated == FALSE) {
      createFile();
    }
  } else {
    Lcd.draw_font(0, 0, "Sensor Hub off-line", 0xffff00, 0, 20);
  }
  /* ==== END OF LOG FILE CREATION etc... ==== */

  draw_rect(170, 140, 70, 40, 0xffffff);
  Lcd.draw_font(180, 150, "TRIG", 0xffffff, 0x000000, 26);

  userConfirm = 0;

  if (Tp.Event_available()) {
    Tp.Get_event_xy(&EVENT, &X, &Y);
    if (EVENT >= 1) {
      if (X >= 170 && Y >= 140 && Y <= 180) {
        Serial.println("TRIG");
        userConfirm = 3;
        triggered = TRUE;
      }
      if (triggered == TRUE || fallDetected == TRUE) {
        if (X >= 20 && X <= 70 && Y >= 50 && Y <= 100) {
          Serial.println("YES");
          userConfirm = 1;
          Lcd.screen_set(0x000000);
          triggered = FALSE;
          triggeredFirstRun = FALSE;
          fallDetected = FALSE;
          fileCreated = FALSE;
        }
        else if (X >= 100 && X <= 150 && Y >= 50 && Y <= 100) {
          Serial.println("NO");
          userConfirm = 2;
          Lcd.screen_set(0x000000);
          triggered = FALSE;
          triggeredFirstRun = FALSE;
          fallDetected = FALSE;
          fileCreated = FALSE;
        }
      }
    }
  }

  if (triggered == TRUE || fallDetected == TRUE) {
    Serial.println("Entered triggered==TRUE");
    if (triggeredFirstRun != TRUE) {
      Lcd.screen_set(0xff007f);
      Lcd.draw_font(20, 30, "Have you fallen?", 0xff007f, 0x000000, 20);
      draw_rect(20, 50, 50, 50, 0x000000);
      Lcd.draw_font(25, 55, "YES", 0x000000, 0xffffff, 20);
      draw_rect(100, 50, 50, 50, 0x000000);
      Lcd.draw_font(105, 55, "NO", 0x000000, 0xffffff, 20);

      triggeredFirstRun = TRUE;
    }
  }

  /* ==== FALL DETECTION LOOP ==== */
  while (firstRead != lastRead) {
    accelLoop();
    accelStateMachine();
    fillDataArray();
  }

  if (userConfirm == 1 || userConfirm == 2) {
    writeToFile();
  }

  Lcd.draw_updata();
}
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

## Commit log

2016-07-15 first commit of the arduino main project file
2016-07-15 add touch event to switch back to main state
2016-08-29 add sketch that pushes battery state to IFTTT via http requests
2016-08-29 add sketch that logs sensor values to a txt file in the local storage
2016-10-05 add display feedback when the sensor is connected/disconnected
2016-10-10 prototype firmware for maker faire rome first commit
2016-11-16 remove battery ifttt sketch
2016-12-06 add sketch to print light data stream to a file in JSON format
2016-12-13 add folder and first sketch to test battery consumption
2017-01-05 add battery test with sleep library
2017-01-31 inserted image
2017-02-07 add sketch that receives a value via SMS and switches background color accordingly
2017-02-07 remove sensor hub offline print from LOG
2017-02-07 add sensor hub online/offline LOG
2017-02-09 absolute path for post image
    need to understand why the relative path doesn’t work :/
2017-02-21 add printing of the whole array and remove wrong bg color after confirming fall
    [inpe-t03_012.ino]
2017-11-20 update sketch to avoid stray 357 error
    [inpe_mfr_UPDATED.ino]
